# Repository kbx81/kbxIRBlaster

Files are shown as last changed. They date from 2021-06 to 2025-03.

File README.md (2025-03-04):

# kbx IR Blaster

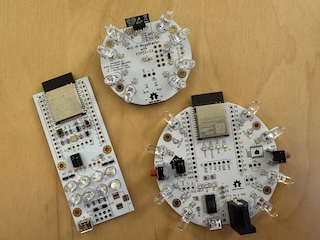
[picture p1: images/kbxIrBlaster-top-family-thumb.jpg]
kbxIrBlasters

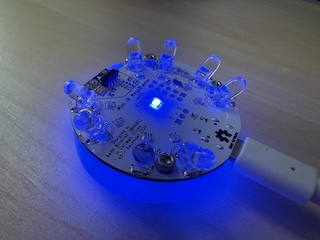
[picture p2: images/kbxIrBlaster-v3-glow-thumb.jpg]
kbxIrBlaster-v3


## What?

Just another ESP32-based IR Blaster. It was designed with [ESPHome](https://esphome.io) in mind but should work fine
with [Tasmota](https://tasmota.github.io/docs/) or any other app, really.

I've created four versions:
- [v4](v4/)
  - Based on ESP32-C6
  - Nearly identical to [v3](v3/) (below) but with minor adjustments/enhancements
- [v3](v3/)
  - Based on ESP32-C3
  - Disc (smaller)
  - One header for (an) off-board emitter(s)
  - Pads for 24 IR LEDs:
    - Eight top-emitting surface mount
    - Eight side-emitting surface mount around the edges of the disc
    - Eight 5 mm LEDs for extra "throw"
- [v2](v2/)
  - Based on ESP32
  - Disc
  - One header for (an) off-board emitter(s)
  - Pads for 16 IR LEDs:
    - Eight top-emitting surface mount
    - Eight 5 mm LEDs for extra "throw" around the perimeter of the PCB
- [v1](v1/)
  - Based on ESP32
  - Rectangular
  - One header for up to four external control channels
  - Pads for up to eight through-hole LEDs, front- and/or back-facing

See the [gallery](GALLERY.md) for more images.

## Why?

After trying this on a perfboard with parts I had laying around, I wanted something more polished and more powerful.
I found [Sparkfun's IR Blaster](https://www.sparkfun.com/products/15031) which is quite nice, tiny and clean but I
quickly realized that its IR output is somewhat weak and would only work if pointed _directly_ at the device it was
intended to control. Rather than hack it up, I chose to draw up my own versions of such a thing. My goal was to make
them substantially more powerful in an effort to "light up a room" with infrared light; that is, you'll probably find
that they work well even when not specifically directed at (if even near) devices you wish to control. I've used an
ESP32 module instead of an ESP8266, as the ESP32 (and its variants) has dedicated hardware for IR data transmission
(the RMT) which makes it more suitable for this purpose, despite that it's otherwise quite overkill.

## How?

Please see the bill of materials (BoM) for the version of interest:
 -  v4 BoM: [Octopart](https://octopart.com/bom-tool/P6YqtNWD), [CSV](v4/kbxIrBlaster_bom.csv)
 -  v3 BoM: [Octopart](https://octopart.com/bom-tool/GUsHZQub), [CSV](v3/kbxIrBlaster_bom.csv)
 -  v2 BoM: [Octopart](https://octopart.com/bom-tool/78rYOXWE), [CSV](v2/kbxIrBlaster_bom.csv)
 -  v1 BoM: [Octopart](https://octopart.com/bom-tool/vDwq4wDr), [CSV](v1/kbxIrBlaster_bom.csv)

I had the PCBs fabricated by [Elecrow](https://www.elecrow.com) but nearly any PCB fabricator should be able to
manufacture these without any issues. I do recommend white soldermask as it will reflect IR best.

The schematic and PCB were drawn in [KiCad](https://www.kicad.org).

## Build Notes

The [v1](v1/) and [v2](v2/) PCBs have a number of solder jumpers on the bottom side that enable each of the FET drivers
to be connected to one of two possible GPIO pins. This allows a single GPIO pin to control all LEDs simultaneously or
they can be broken apart onto separate GPIO pins. Labels on the underside of the PCBs indicate what jumpers are
connected to what LEDs.

_Note that the solder jumpers **must be bridged** one way or the other; if this is not done, the FETs (and consequently
the LEDs they drive) will not activate!_ When you build one, be sure to complete this step or you'll be left in the
dark. (Punny, I know.)

## Add-ons

An FS1000A (such as [this one](https://www.amazon.com/HiLetgo-Wireless-Transmitter-Receiver-Raspberry/dp/B01DKC2EY4/))
or similar 433 MHz transmitter module may be connected as indicated on the PCB allowing the device to double as an RF
remote controller. On the [v1](v1/) PCB, bridge JP6 to enable this and then connect the module to pins 4, 5, and 6 on
J2. On the [v2](v2/) PCB, simply connect the transmitter to J8. When doing so, be sure to orient the module correctly
or tragedy may result.

## Usage

See my [ESPHome-configs](https://github.com/kbx81/esphome-configs) repository for example
[ESPHome](https://esphome.io) configuration you may use with your IR blaster. Enjoy!

 ## Legal stuff and License

The circuit schematics and PCB found here are licensed under the
 [Creative Commons Attribution-ShareAlike 4.0 International License](http://creativecommons.org/licenses/by-sa/4.0/).



_Happy building!_

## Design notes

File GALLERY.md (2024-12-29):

# kbx IR Blaster

## Image Gallery

Click on an image to see the high-resolution version.

kbxIrBlasters

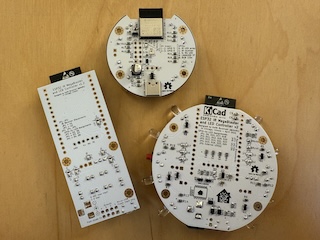
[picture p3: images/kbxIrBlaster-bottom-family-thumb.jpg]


### v3

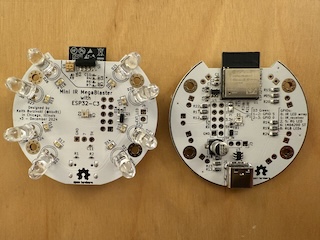
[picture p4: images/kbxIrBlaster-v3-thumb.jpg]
kbxIrBlaster-v3


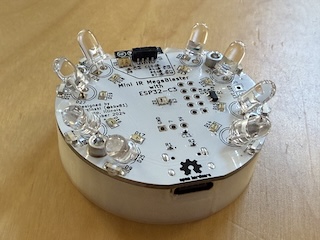
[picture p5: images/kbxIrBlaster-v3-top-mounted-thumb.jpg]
kbxIrBlaster-v3


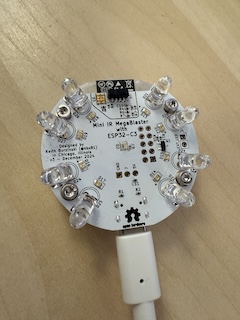
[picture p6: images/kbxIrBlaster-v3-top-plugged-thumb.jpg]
kbxIrBlaster-v3


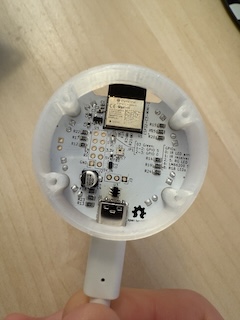
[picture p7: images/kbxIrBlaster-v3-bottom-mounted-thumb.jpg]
kbxIrBlaster-v3


kbxIrBlaster-v3

### v2

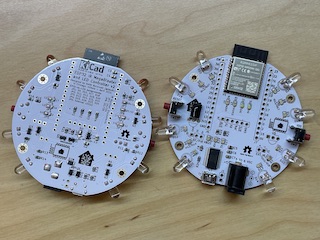
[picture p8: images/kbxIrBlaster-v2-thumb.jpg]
kbxIrBlaster-v2


As seen with the Raspberry Pi NOIR camera:

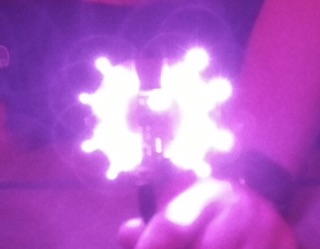
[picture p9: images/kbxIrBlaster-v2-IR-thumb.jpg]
kbxIrBlaster-v2-IR


### v1

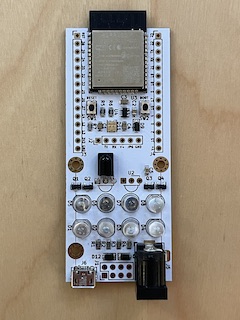
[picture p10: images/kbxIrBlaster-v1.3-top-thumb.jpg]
kbxIrBlaster-v1.3-top


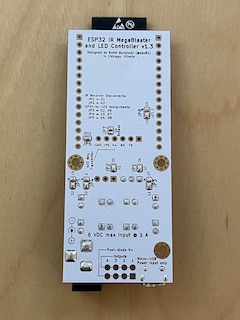
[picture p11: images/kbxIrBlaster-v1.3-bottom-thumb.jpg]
kbxIrBlaster-v1.3-bottom


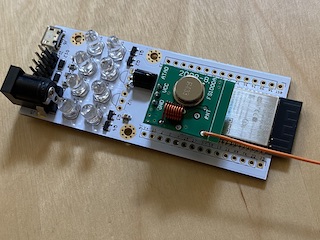
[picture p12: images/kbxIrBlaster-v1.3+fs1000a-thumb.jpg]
kbxIrBlaster+fs1000a


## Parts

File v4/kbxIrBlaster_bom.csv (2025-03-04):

Component | Quantity Per PCB | References | Value | MPN1 | MPN2 | Footprint | Population
1 | 6 | C1 C7 C9 C10 C12 C13 | 100n | CC0402KRX5R6BB104 |  | C_0402_1005Metric
2 | 3 | C2 C8 C11 | 1u | CC0402KRX5R6BB105 |  | C_0402_1005Metric
3 | 1 | C4 | 100u | UWR1A101MCL1GB |  | CP_Elec_5x5.4
4 | 3 | C3 C5 C6 | 10u/20% | CC0603MRX5R6BB106 |  | C_0603_1608Metric
5 | 8 | D12 D13 D14 D15 D16 D17 D18 D19 | APT2012F3C | APT2012F3C |  | LED_0805_2012Metric
6 | 1 | D3 | HW_LED | APB3227SURKZGC |  | LED_Cree-PLCC4_3.2x2.8mm_CCW
7 | 8 | D20 D21 D22 D23 D24 D25 D26 D27 | LTE-4206 | LTE-4206 |  | LED_D5.0mm
8 | 8 | D4 D5 D6 D7 D8 D9 D10 D11 | VSMB10940 | VSMB10940 |  | LED_Kingbright_KPA-3010_3x2x1mm
9 | 2 | D1 D2 | WS2812B | WS2812B-2020 |  | LED_WS2812B-2020_PLCC4_2.0x2.0mm
10 | 1 | FB1 | 600R/2A | MPZ1608S221ATA00 |  | L_0603_1608Metric
11 | 1 | J1 | HRO TYPE-C 31-M-12 | HRO TYPE-C 31-M-12 |  | USB_C_Receptacle_HRO_TYPE-C-31-M-12
12 | 1 | Q1 | PMV164ENEAR | PMV164ENEAR |  | SOT-23
13 | 4 | R24 R25 R26 R27 | 27 | RC0805FR-0727RL |  | R_0805_2012Metric
14 | 4 | R14 R15 R16 R17 | 47 | RC0805JR-0747RL |  | R_0805_2012Metric
15 | 4 | R19 R20 R21 R22 | 56 | RC0805JR-0756RL |  | R_0805_2012Metric
16 | 5 | R3 R10 R11 R12 R18 | 100R | RC0402JR-07100RL |  | R_0402_1005Metric
17 | 2 | R1 R2 | 5k1 | RC0402JR-075K1L |  | R_0402_1005Metric
18 | 8 | R4 R5 R6 R7 R8 R9 R13 R23 | 10k | RC0402JR-0710KL |  | R_0402_1005Metric
19 | 2 | SW1 SW2 | BOOT | KMR2 |  | SW_Push_1P1T_NO_CK_KMR2
20 | 2 | U6 U7 | 74LVC2G157 | 74LVC2G157 |  | VSSOP-8_2.3x2mm_P0.5mm
21 | 1 | U4 | AP2112K-3.3 | AP2112K-3.3TRG1 |  | SOT-23-5
22 | 1 | U1 | ESP32-C6-MINI-1/U | ESP32-C6-MINI-1 |  | ESP32-C6-MINI-1
23 | 1 | U2 | LM66200 | LM66200 |  | SOT-583-8
24 | 1 | U5 | TSOP752xx | TSOP75238 |  | Vishay_TSOP752_Horizontal
25 | 1 | U3 | USBLC6-2SC6 | USBLC6-2SC6 |  | SOT-23-6

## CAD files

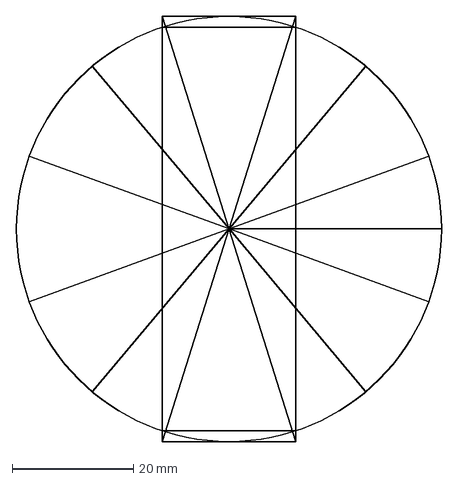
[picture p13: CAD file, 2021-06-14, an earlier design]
v2/kbxIrBlasterDiscPCB.dxf
70.0 x 70.0 mm

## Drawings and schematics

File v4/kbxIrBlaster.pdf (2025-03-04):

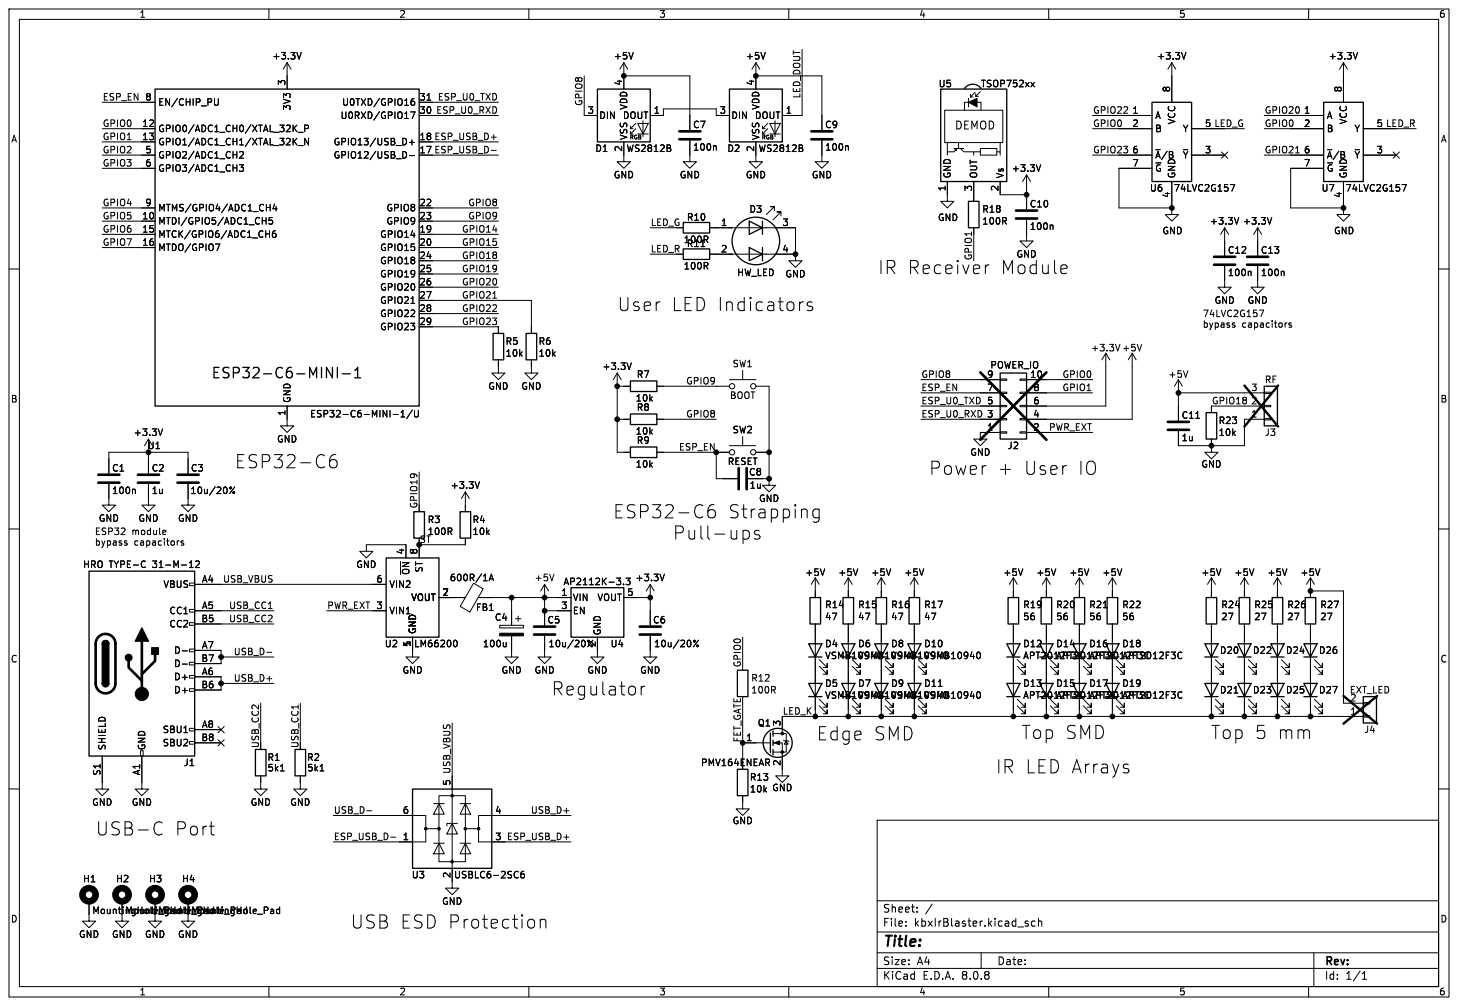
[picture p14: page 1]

3 U0RXD/GPIO17 30 U0TXD/GPIO16 31 GPIO2/ADC1_CH2 5 GPIO3/ADC1_CH3 6 EN/CHIP_PU 8 MTMS/GPIO4/ADC1_CH4 9U1 ESP32-C6-MINI-1/U GND

Id: 1/1 Title: File: kbxIrBlaster.kicad_sch Sheet: / GND

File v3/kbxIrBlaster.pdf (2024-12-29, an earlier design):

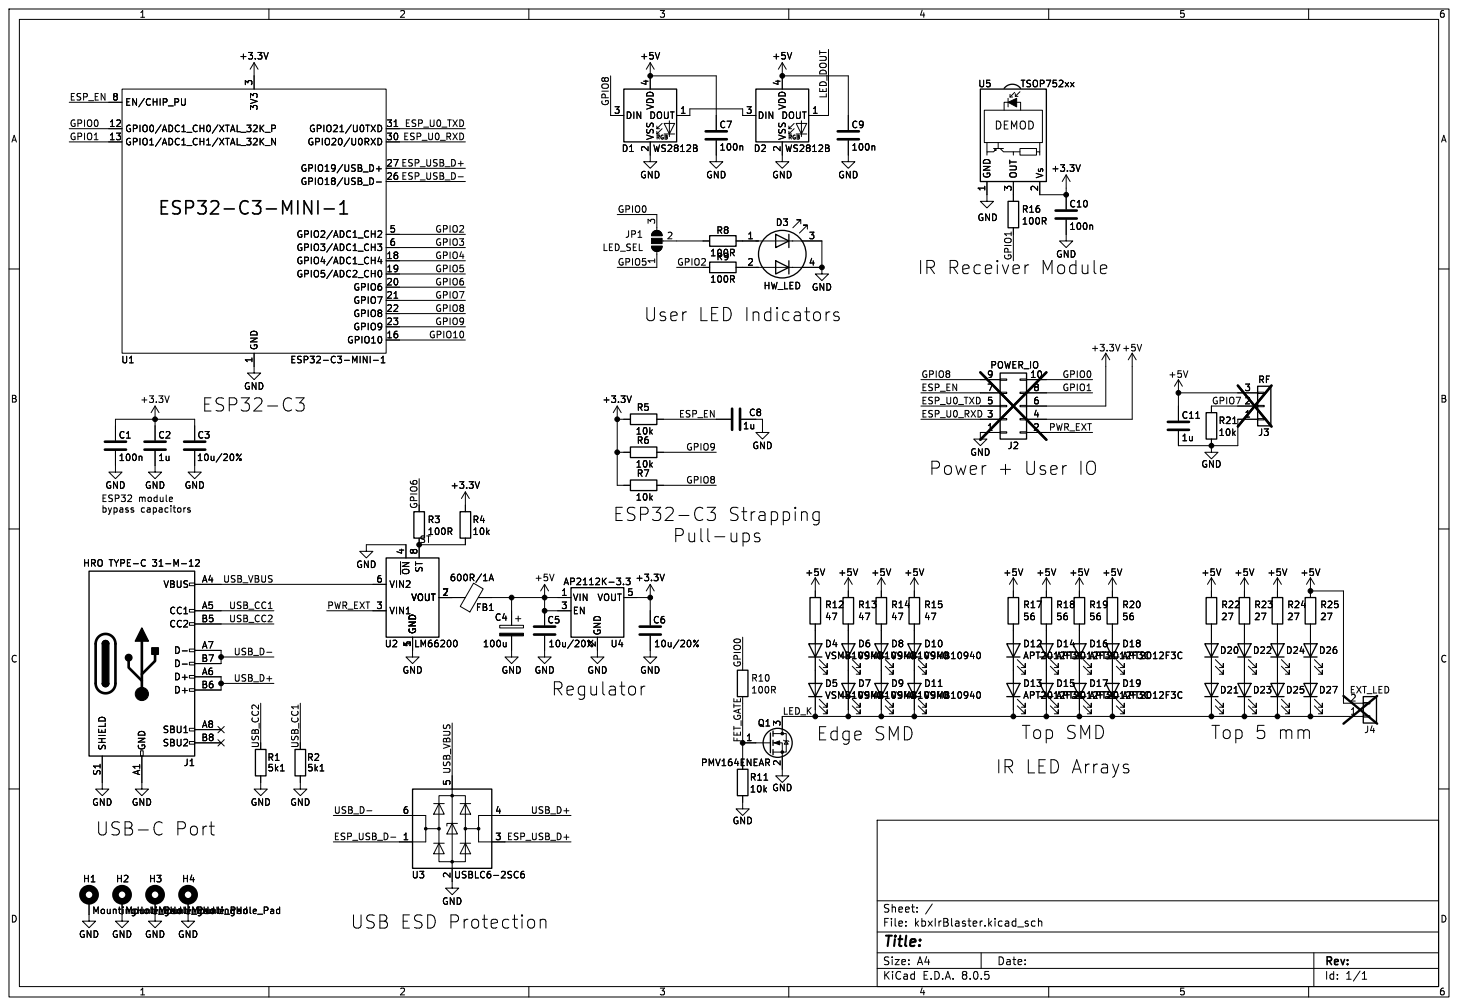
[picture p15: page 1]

2 EN 3 VOUT 5 U4 AP2112K-3.3 GND GND

Id: 1/1 Title: File: kbxIrBlaster.kicad_sch Sheet: /

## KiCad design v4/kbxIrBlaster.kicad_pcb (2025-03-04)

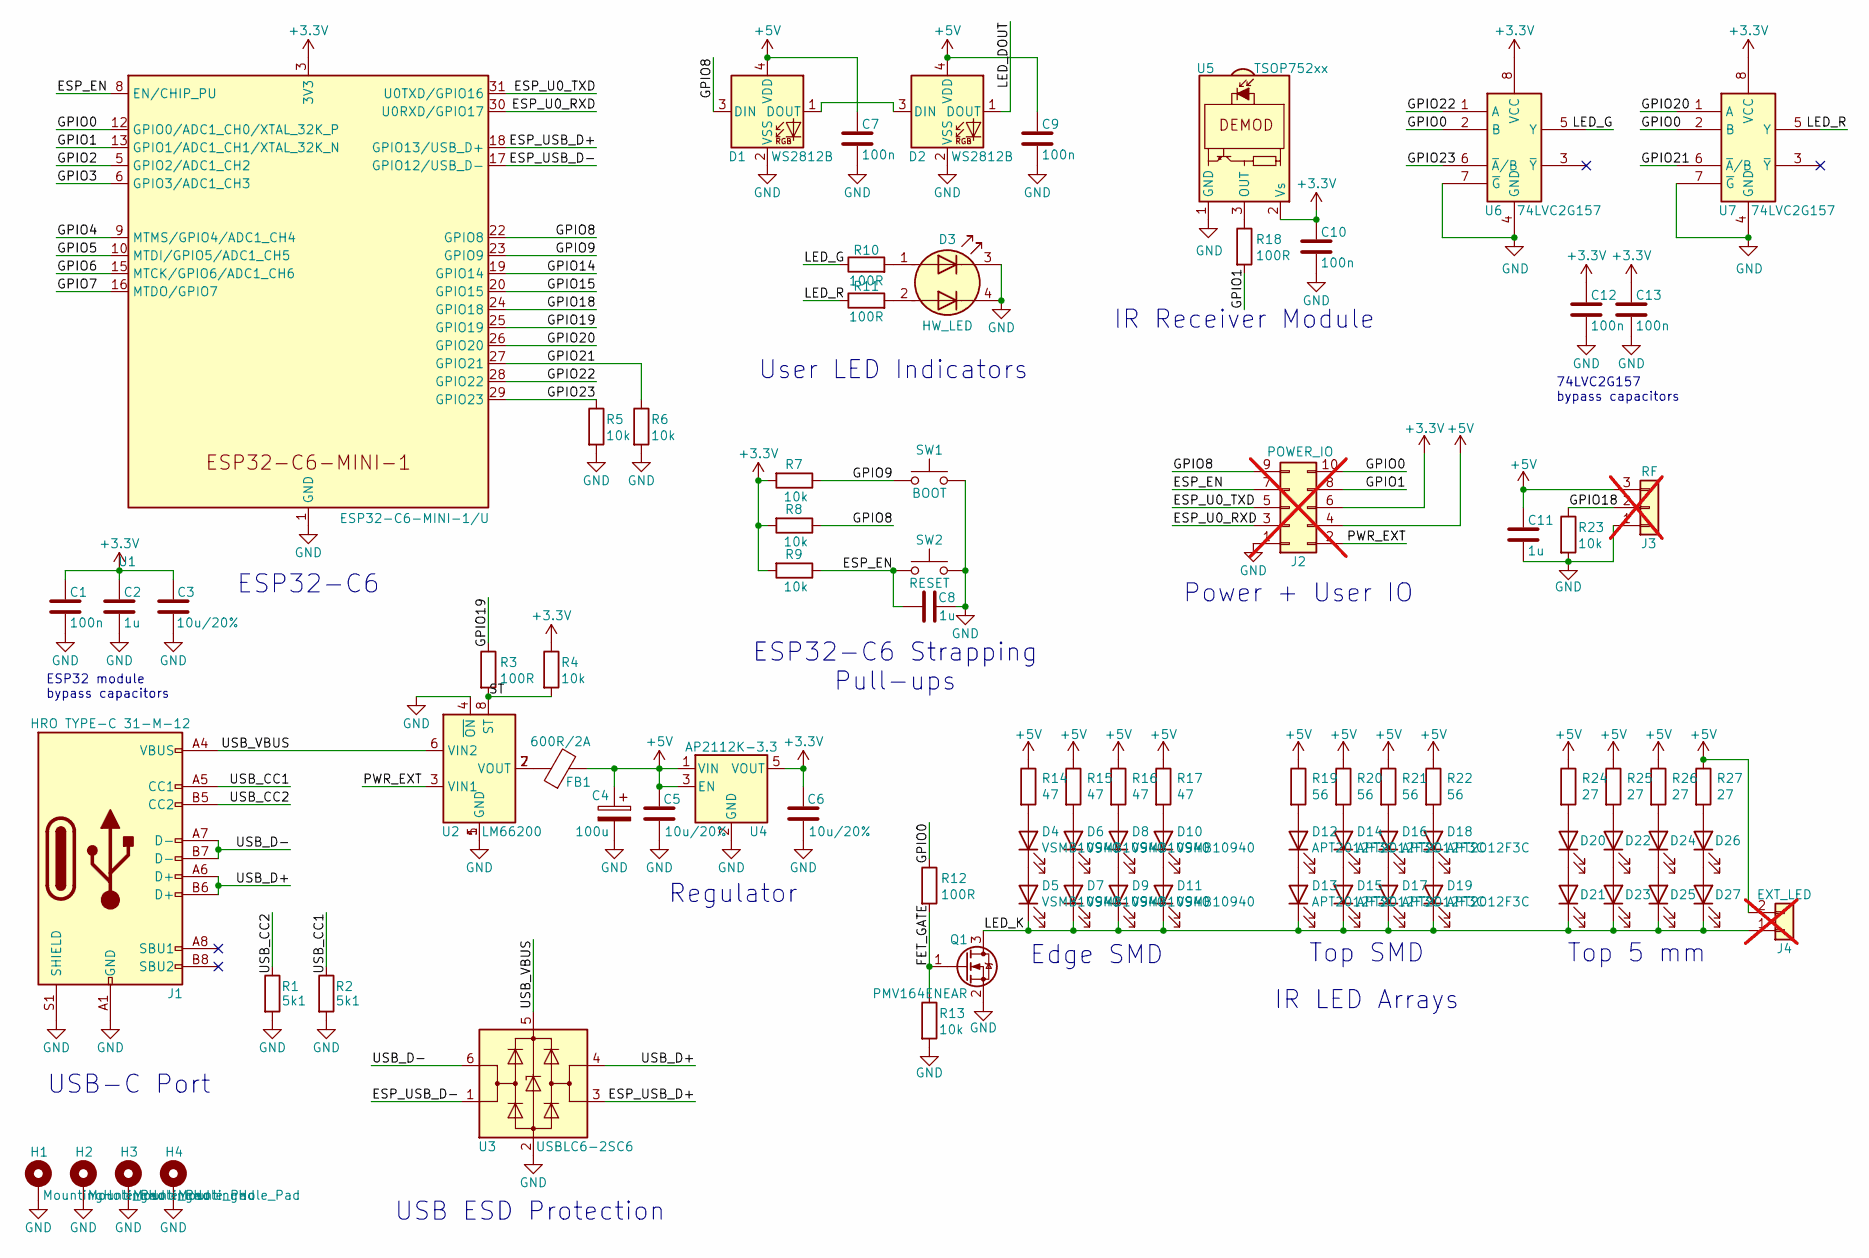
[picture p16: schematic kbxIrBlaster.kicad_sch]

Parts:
C1, C7, C9, C10, C12, C13: 100n; C_0402_1005Metric; MPN1 CC0402KRX5R6BB104
C2, C8, C11: 1u; C_0402_1005Metric; MPN1 CC0402KRX5R6BB105
C3, C5, C6: 10u/20%; C_0603_1608Metric; MPN1 CC0603MRX5R6BB106
C4: 100u; CP_Elec_5x5.4; MPN1 UWR1A101MCL1GB
D1, D2: WS2812B; LED_WS2812B-2020_PLCC4_2.0x2.0mm; MPN1 WS2812B-2020
D3: HW_LED; LED_Cree-PLCC4_3.2x2.8mm_CCW; MPN1 APB3227SURKZGC
D4, D5, D6, D7, D8, D9, D10, D11: VSMB10940; LED_Kingbright_KPA-3010_3x2x1mm; MPN1 VSMB10940
D12, D13, D14, D15, D16, D17, D18, D19: APT2012F3C; LED_0805_2012Metric; MPN1 APT2012F3C
D20, D21, D22, D23, D24, D25, D26, D27: LTE-4206; LED_D5.0mm; MPN1 LTE-4206
FB1: 600R/2A; L_0603_1608Metric; MPN1 MPZ1608S221ATA00
H1, H2, H3, H4: MountingHole_Pad; MountingHole_2.5mm_Pad_Via
J1: HRO TYPE-C 31-M-12; USB_C_Receptacle_HRO_TYPE-C-31-M-12; MPN1 HRO TYPE-C 31-M-12
J2: POWER_IO; PinSocket_2x05_P2.54mm_Vertical; not fitted
J3: RF; PinSocket_1x03_P2.54mm_Vertical; not fitted
J4: EXT_LED; PinSocket_1x02_P2.54mm_Vertical; not fitted
Q1: PMV164ENEAR; SOT-23; MPN1 PMV164ENEAR
R1, R2: 5k1; R_0402_1005Metric; MPN1 RC0402JR-075K1L
R3, R10, R11, R12, R18: 100R; R_0402_1005Metric; MPN1 RC0402JR-07100RL
R4, R5, R6, R7, R8, R9, R13, R23: 10k; R_0402_1005Metric; MPN1 RC0402JR-0710KL
R14, R15, R16, R17: 47; R_0805_2012Metric; MPN1 RC0805JR-0747RL
R19, R20, R21, R22: 56; R_0805_2012Metric; MPN1 RC0805JR-0756RL
R24, R25, R26, R27: 27; R_0805_2012Metric; MPN1 RC0805FR-0727RL
SW1: BOOT; SW_Push_1P1T_NO_CK_KMR2; MPN1 KMR2
SW2: RESET; SW_Push_1P1T_NO_CK_KMR2; MPN1 KMR2
U1: ESP32-C6-MINI-1/U; ESP32-C6-MINI-1; MPN1 ESP32-C6-MINI-1
U2: LM66200; SOT-583-8; MPN1 LM66200
U3: USBLC6-2SC6; SOT-23-6; MPN1 USBLC6-2SC6
U4: AP2112K-3.3; SOT-23-5; MPN1 AP2112K-3.3TRG1
U5: TSOP752xx; Vishay_TSOP752_Horizontal; MPN1 TSOP75238
U6, U7: 74LVC2G157; VSSOP-8_2.3x2mm_P0.5mm; MPN1 74LVC2G157

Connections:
+3.3V: C1.1, C2.1, C3.1, C6.1, C10.1, C12.1, C13.1, J2.6, R4.1, R7.2, R8.2, R9.2, U1.3 (3V3), U4.5 (VOUT), U5.2 (Vs), U6.8 (VCC), U7.8 (VCC)
+5V: C4.1, C5.1, C7.1, C9.1, C11.1, D1.4 (VDD), D2.4 (VDD), FB1.2, J2.4, J3.3, J4.2, R14.1, R15.1, R16.1, R17.1, R19.1, R20.1, R21.1, R22.1, R24.1, R25.1, R26.1, R27.1, U4.1 (VIN), U4.3 (EN)
/ESP_EN: C8.1, J2.7, R9.1, SW2.1, U1.8 (EN/CHIP_PU)
/ESP_U0_RXD: J2.3, U1.30 (U0RXD/GPIO17)
/ESP_U0_TXD: J2.5, U1.31 (U0TXD/GPIO16)
/ESP_USB_D+: U1.18 (GPIO13/USB_D+), U3.3 (I/O2)
/ESP_USB_D-: U1.17 (GPIO12/USB_D-), U3.1 (I/O1)
/FET_GATE: Q1.1 (G), R12.2, R13.1
/GPIO0: J2.10, R12.1, U1.12 (GPIO0/ADC1_CH0/XTAL_32K_P), U6.2 (B), U7.2 (B)
/GPIO1: J2.8, R18.2, U1.13 (GPIO1/ADC1_CH1/XTAL_32K_N)
/GPIO2: U1.5 (GPIO2/ADC1_CH2)
/GPIO3: U1.6 (GPIO3/ADC1_CH3)
/GPIO4: U1.9 (MTMS/GPIO4/ADC1_CH4)
/GPIO5: U1.10 (MTDI/GPIO5/ADC1_CH5)
/GPIO6: U1.15 (MTCK/GPIO6/ADC1_CH6)
/GPIO7: U1.16 (MTDO/GPIO7)
/GPIO8: D1.3 (DIN), J2.9, R8.1, U1.22 (GPIO8)
/GPIO9: R7.1, SW1.1, U1.23 (GPIO9)
/GPIO14: U1.19 (GPIO14)
/GPIO15: U1.20 (GPIO15)
/GPIO18: J3.2, R23.1, U1.24 (GPIO18)
/GPIO19: R3.1, U1.25 (GPIO19)
/GPIO20: U1.26 (GPIO20), U7.1 (A)
/GPIO21: R6.1, U1.27 (GPIO21), U7.6 (~A/B)
/GPIO22: U1.28 (GPIO22), U6.1 (A)
/GPIO23: R5.1, U1.29 (GPIO23), U6.6 (~A/B)
/LED_DOUT: D2.1 (DOUT)
/LED_G: R10.1, U6.5 (Y)
/LED_K: D5.1 (K), D7.1 (K), D9.1 (K), D11.1 (K), D13.1 (K), D15.1 (K), D17.1 (K), D19.1 (K), D21.1 (K), D23.1 (K), D25.1 (K), D27.1 (K), J4.1, Q1.3 (D)
/LED_R: R11.1, U7.5 (Y)
/PWR_EXT: J2.2, U2.3 (VIN1)
/ST: R3.2, R4.2, U2.8 (ST)
/USB_CC1: J1.A5 (CC1), R2.1
/USB_CC2: J1.B5 (CC2), R1.1
/USB_D+: J1.A6 (D+), J1.B6 (D+), U3.4 (I/O2)
/USB_D-: J1.A7 (D-), J1.B7 (D-), U3.6 (I/O1)
/USB_VBUS: J1.A4 (VBUS), J1.A9 (VBUS), J1.B4 (VBUS), J1.B9 (VBUS), U2.6 (VIN2), U3.5 (VBUS)
GND: C1.2, C2.2, C3.2, C4.2, C5.2, C6.2, C7.2, C8.2, C9.2, C10.2, C11.2, C12.2, C13.2, D1.2 (VSS), D2.2 (VSS), D3.3 (K1), D3.4 (K2), H1.1, H2.1, H3.1, H4.1, J1.A1 (GND), J1.A12 (GND), J1.B1 (GND), J1.B12 (GND), J1.S1 (SHIELD), J2.1, J3.1, Q1.2 (S), R1.2, R2.2, R5.2, R6.2, R13.2, R23.2, SW1.2, SW2.2, U1.1 (GND), U1.2 (GND), U1.11 (GND), U1.14 (GND), U1.36 (GND), U1.37 (GND), U1.38 (GND), U1.39 (GND), U1.40 (GND), U1.41 (GND), U1.42 (GND), U1.43 (GND), U1.44 (GND), U1.45 (GND), U1.46 (GND), U1.47 (GND), U1.48 (GND), U1.49 (GND), U1.50 (GND), U1.51 (GND), U1.52 (GND), U1.53 (GND), U2.1 (GND), U2.4 (~ON), U2.5 (GND), U3.2 (GND), U4.2 (GND), U5.1 (GND), U5.4 (GND), U6.4 (GND), U6.7 (~G), U7.4 (GND), U7.7 (~G)
unnamed: D1.1 (DOUT), D2.3 (DIN)
unnamed: D3.1 (A1), R10.2
unnamed: D3.2 (A2), R11.2
unnamed: D4.2 (A), R14.2
unnamed: D4.1 (K), D5.2 (A)
unnamed: D6.2 (A), R15.2
unnamed: D6.1 (K), D7.2 (A)
unnamed: D8.2 (A), R16.2
unnamed: D8.1 (K), D9.2 (A)
unnamed: D10.2 (A), R17.2
unnamed: D10.1 (K), D11.2 (A)
unnamed: D12.2 (A), R19.2
unnamed: D12.1 (K), D13.2 (A)
unnamed: D14.2 (A), R20.2
unnamed: D14.1 (K), D15.2 (A)
unnamed: D16.2 (A), R21.2
unnamed: D16.1 (K), D17.2 (A)
unnamed: D18.2 (A), R22.2
unnamed: D18.1 (K), D19.2 (A)
unnamed: D20.2 (A), R24.2
unnamed: D20.1 (K), D21.2 (A)
unnamed: D22.2 (A), R25.2
unnamed: D22.1 (K), D23.2 (A)
unnamed: D24.2 (A), R26.2
unnamed: D24.1 (K), D25.2 (A)
unnamed: D26.2 (A), R27.2
unnamed: D26.1 (K), D27.2 (A)
unnamed: FB1.1, U2.2 (VOUT), U2.7 (VOUT)
unnamed: R18.1, U5.3 (OUT)

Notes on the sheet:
Top SMD
Edge SMD
74LVC2G157 bypass capacitors
User LED Indicators
Power + User IO
ESP32-C6
USB-C Port
USB ESD Protection
Top 5 mm
ESP32-C6 Strapping Pull-ups
IR Receiver Module
IR LED Arrays
Regulator
ESP32 module bypass capacitors

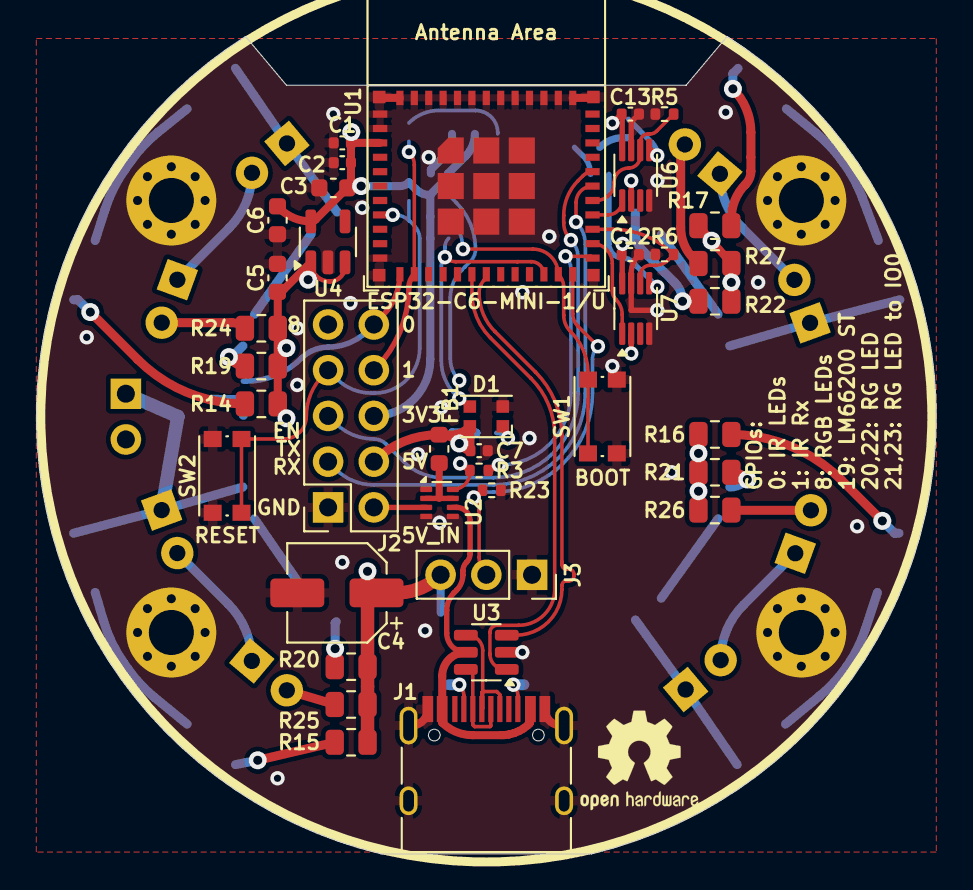
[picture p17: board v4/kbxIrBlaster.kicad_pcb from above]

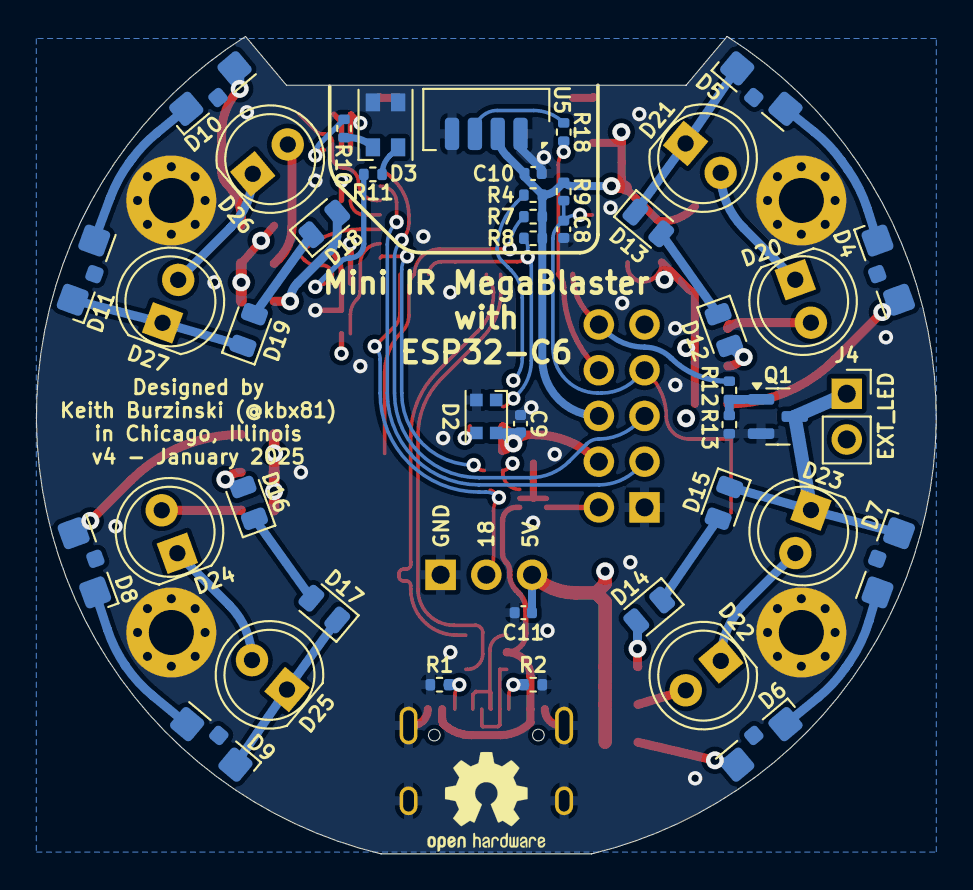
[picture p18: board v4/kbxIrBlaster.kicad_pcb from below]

Board: 4 copper layers, 50.0 x 45.4 mm, 86 parts (44 on the bottom side), 58 nets.

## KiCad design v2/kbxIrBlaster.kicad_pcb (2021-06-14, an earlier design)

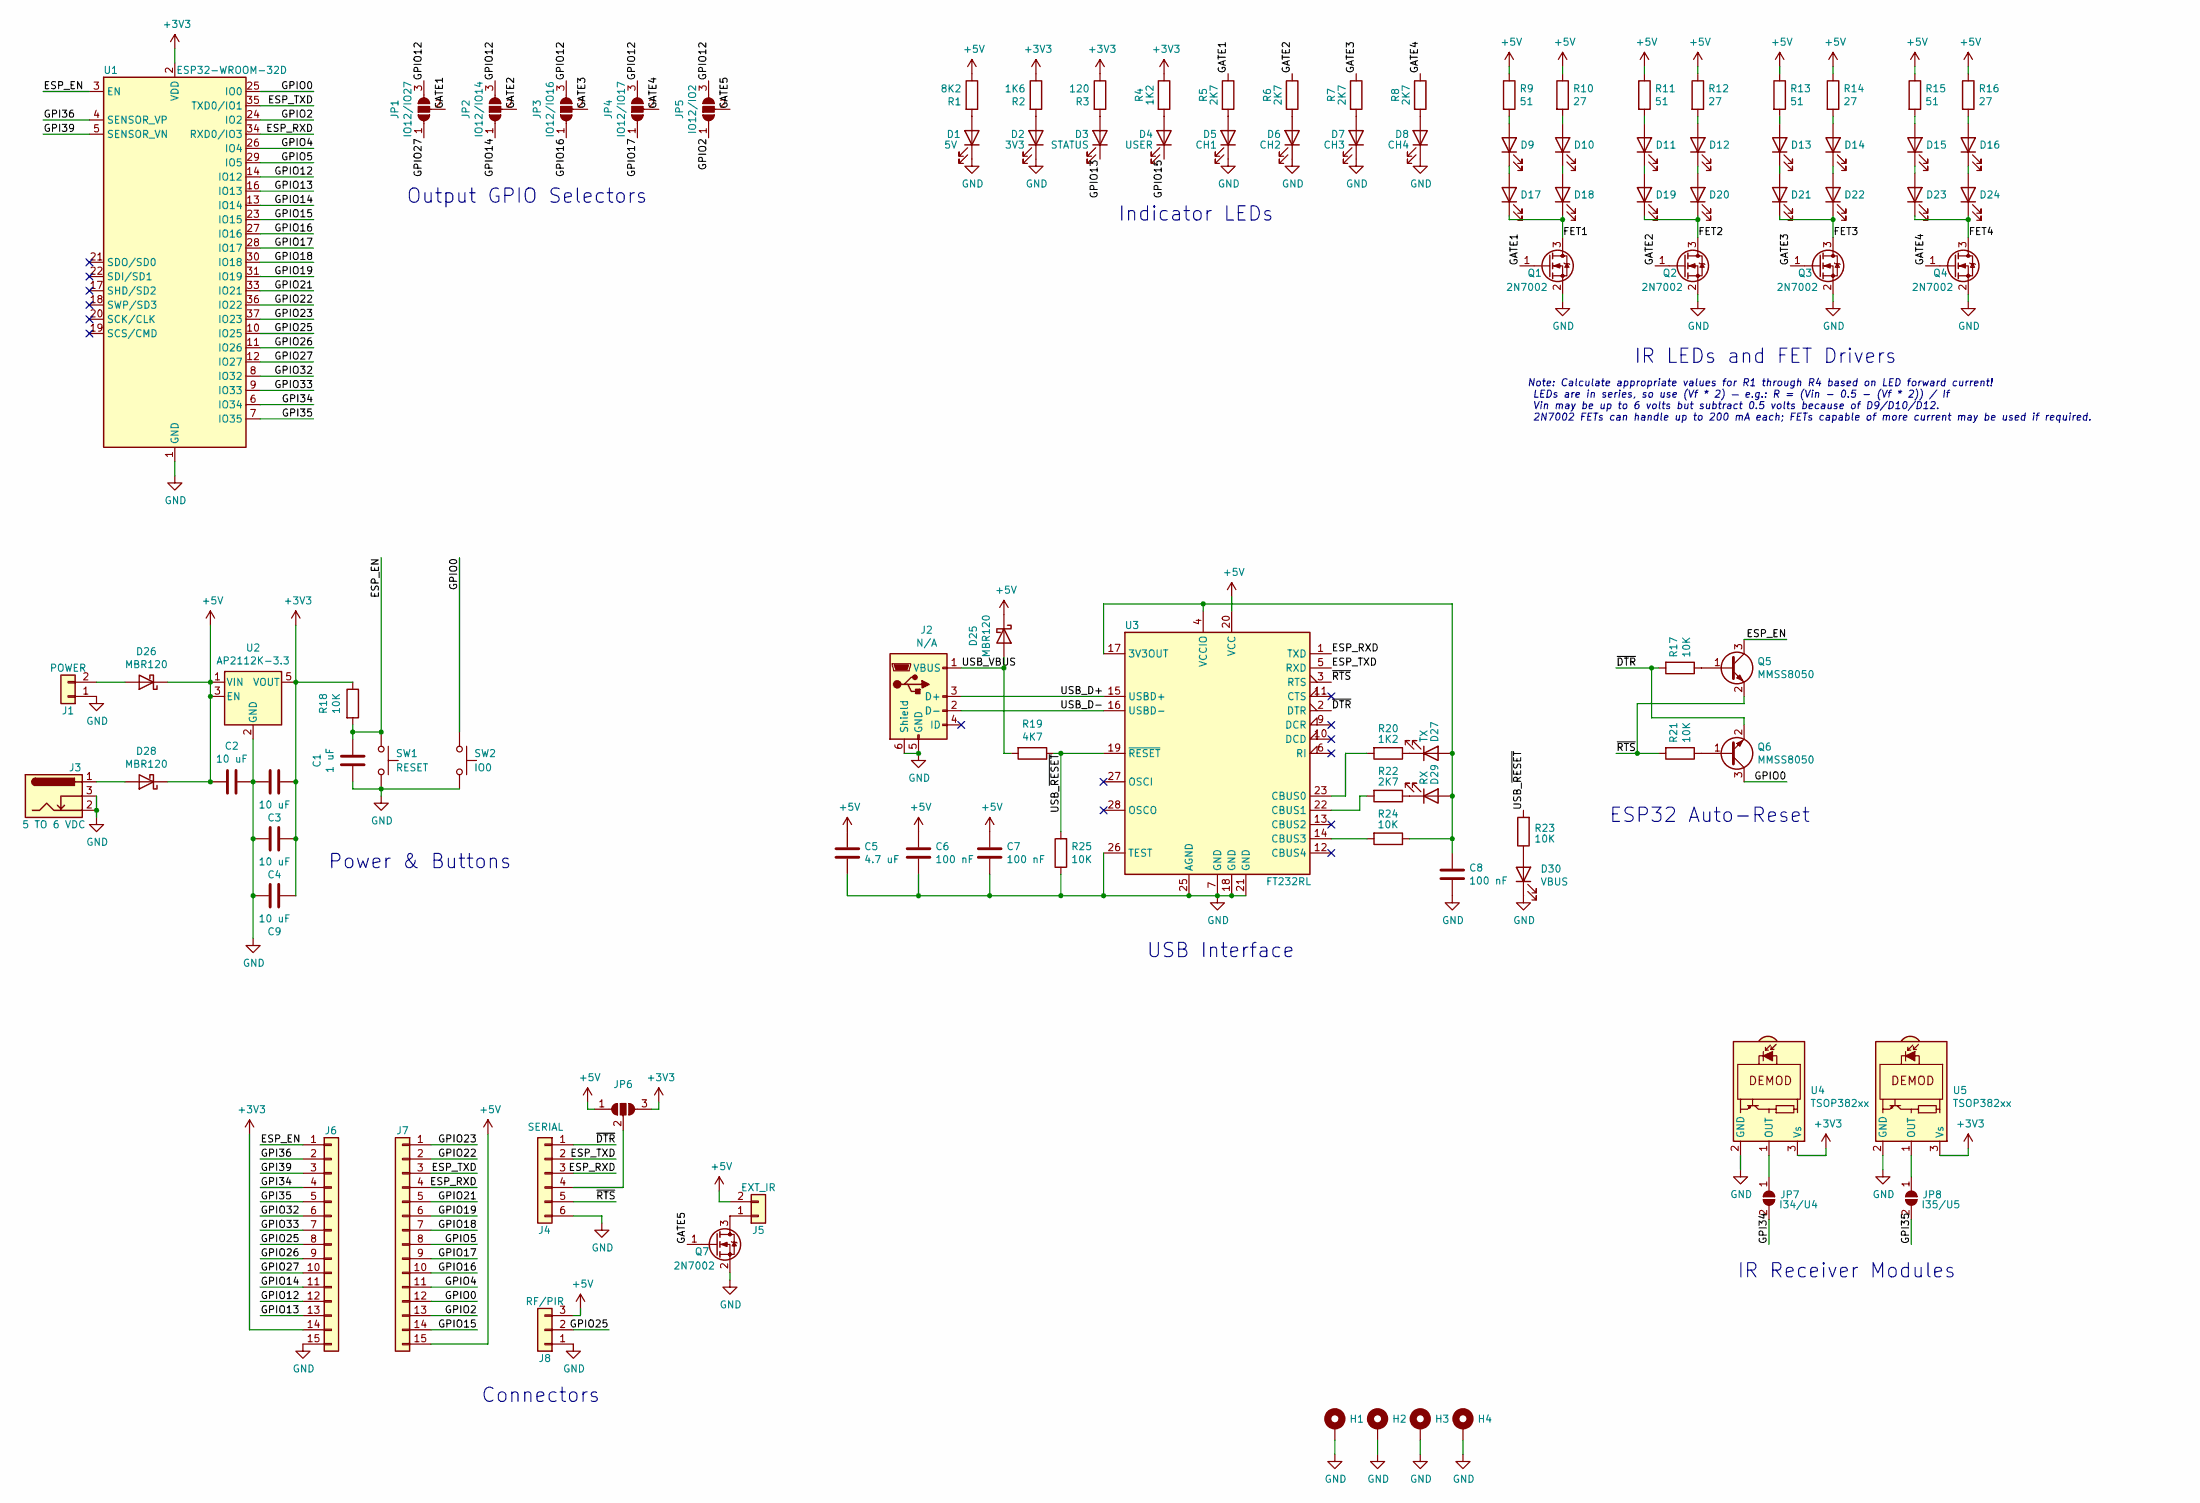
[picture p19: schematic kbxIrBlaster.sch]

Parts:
C1: 1 uF; C_0805_2012Metric; MPN1 C0805C105K4RACTU
C2, C3, C4, C9: 10 uF; C_0805_2012Metric; MPN1 GRM21BC81C106ME15L
C5: 4.7 uF; C_0805_2012Metric; MPN1 C2012X5R1H475K125AB
C6, C7, C8: 100 nF; C_0805_2012Metric; MPN1 CC0805KRX7R7BB104
D1: 5V; LED_0805_2012Metric; MPN1 LSM0805543V
D2: 3V3; LED_0805_2012Metric; MPN1 LSM0805543V
D3: STATUS; LED_0805_2012Metric; MPN1 APT2012SECK
D4: USER; LED_0805_2012Metric; MPN1 APT2012SYCK
D5: CH1; LED_0805_2012Metric; MPN1 APT2012EC
D6: CH2; LED_0805_2012Metric; MPN1 APT2012EC
D7: CH3; LED_0805_2012Metric; MPN1 APT2012EC
D8: CH4; LED_0805_2012Metric; MPN1 APT2012EC
D9, D17: CH1; LED_0805_2012Metric; MPN1 APT2012F3C
D10, D18: CH1; LED_D5.0mm; MPN1 LTE-4206
D11, D19: CH2; LED_0805_2012Metric; MPN1 APT2012F3C
D12, D20: CH2; LED_D5.0mm; MPN1 LTE-4206
D13, D21: CH3; LED_0805_2012Metric; MPN1 APT2012F3C
D14, D22: CH3; LED_D5.0mm; MPN1 LTE-4206
D15, D23: CH4; LED_0805_2012Metric; MPN1 APT2012F3C
D16, D24: CH4; LED_D5.0mm; MPN1 LTE-4206
D25, D26, D28: MBR120; D_SOD-123F; MPN1 MBR120VLSFT1G
D27: TX; LED_0805_2012Metric; MPN1 APT2012VBC/D
D29: RX; LED_0805_2012Metric; MPN1 APT2012EC
D30: VBUS; LED_0805_2012Metric; MPN1 APT2012ZGCK
H1, H2, H3, H4: -; MountingHole_2.5mm_Pad_Via
J1: POWER; PinHeader_1x02_P2.54mm_Vertical
J2: N/A; USB_Micro-B_Molex-105017-0001; MPN1 105017-0001
J3: 5 TO 6 VDC; BarrelJack_Horizontal; MPN1 163-179PH-EX
J4: SERIAL; PinHeader_1x06_P2.54mm_Vertical
J5: EXT_IR; PinHeader_1x02_P2.54mm_Vertical
J6, J7: IO; PinHeader_1x15_P2.54mm_Vertical
J8: RF/PIR; PinHeader_1x03_P2.54mm_Vertical
JP1: IO12/IO27; SolderJumper-3_P1.3mm_Open_RoundedPad1.0x1.5mm
JP2: IO12/IO14; SolderJumper-3_P1.3mm_Open_RoundedPad1.0x1.5mm
JP3: IO12/IO16; SolderJumper-3_P1.3mm_Open_RoundedPad1.0x1.5mm
JP4: IO12/IO17; SolderJumper-3_P1.3mm_Open_RoundedPad1.0x1.5mm
JP5: IO12/IO2; SolderJumper-3_P1.3mm_Open_RoundedPad1.0x1.5mm
JP6: 5V/3V3; SolderJumper-3_P1.3mm_Open_RoundedPad1.0x1.5mm
JP7: I34/U4; SolderJumper-2_P1.3mm_Open_RoundedPad1.0x1.5mm
JP8: I35/U5; SolderJumper-2_P1.3mm_Open_RoundedPad1.0x1.5mm
Q1, Q2, Q3, Q4, Q7: 2N7002; SOT-23; MPN1 2N7002-7-F
Q5, Q6: MMSS8050; SOT-23; MPN1 MMSS8050
R1: 8K2; R_0805_2012Metric; MPN1 RT0805FRE078K2L
R2: 1K6; R_0805_2012Metric; MPN1 RT0805FRE071K6L
R3: 120; R_0805_2012Metric; MPN1 RT0805FRE07120RL
R4, R20: 1K2; R_0805_2012Metric; MPN1 RT0805FRE072K7L
R5, R6, R7, R8, R22: 2K7; R_0805_2012Metric; MPN1 RT0805FRE072K7L
R9, R11, R13, R15: 51; R_0805_2012Metric; MPN1 RC0805FR-0751RL
R10, R12, R14, R16: 27; R_0805_2012Metric; MPN1 RC0805FR-0727RL
R17, R18, R21, R23, R24, R25: 10K; R_0805_2012Metric; MPN1 RC0805FR-0710KL
R19: 4K7; R_0805_2012Metric; MPN1 RT0805FRE074K7L
SW1: RESET; SW_Tactile_SPST_Angled_PTS645Vx58-2LFS; MPN1 PTS645VK582LFS
SW2: IO0; SW_Tactile_SPST_Angled_PTS645Vx58-2LFS; MPN1 PTS645VK582LFS
U1: ESP32-WROOM-32D; ESP32-WROOM-32; MPN1 ESP32-WROOM-32D
U2: AP2112K-3.3; SOT-23-5; MPN1 AP2112M-3.3TRG1
U3: FT232RL; SSOP-28_5.3x10.2mm_P0.65mm; MPN1 FT232RL
U4: TSOP382xx; Vishay_MINICAST-3Pin; MPN1 TSOP38238
U5: TSOP382xx; Vishay_MINICAST-3Pin; MPN1 TSOP38256

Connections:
+3V3: C3.2, C4.2, C9.2, J6.14, JP6.3 (B), R2.1, R3.1, R4.1, R18.1, U1.2 (VDD), U2.5 (VOUT), U4.3 (Vs), U5.3 (Vs)
+5V: C2.2, C5.1, C6.1, C7.1, D25.1 (K), D26.1 (K), D28.1 (K), J5.2, J7.15, J8.3, JP6.1 (A), R1.1, R9.1, R10.1, R11.1, R12.1, R13.1, R14.1, R15.1, R16.1, U2.1 (VIN), U2.3 (EN), U3.20 (VCC)
/ESP_EN: C1.1, J6.1, Q5.3 (C), R18.2, SW1.1, U1.3 (EN)
/ESP_RXD: J4.3, J7.4, U1.34 (RXD0/IO3), U3.1 (TXD)
/ESP_TXD: J4.2, J7.3, U1.35 (TXD0/IO1), U3.5 (RXD)
/FET1: D17.1 (K), D18.1 (K), Q1.3 (D)
/FET2: D19.1 (K), D20.1 (K), Q2.3 (D)
/FET3: D21.1 (K), D22.1 (K), Q3.3 (D)
/FET4: D23.1 (K), D24.1 (K), Q4.3 (D)
/GATE1: JP1.2 (C), Q1.1 (G), R5.1
/GATE2: JP2.2 (C), Q2.1 (G), R6.1
/GATE3: JP3.2 (C), Q3.1 (G), R7.1
/GATE4: JP4.2 (C), Q4.1 (G), R8.1
/GATE5: JP5.2 (C), Q7.1 (G)
/GPI34: J6.4, JP7.2 (B), U1.6 (IO34)
/GPI35: J6.5, JP8.2 (B), U1.7 (IO35)
/GPI36: J6.2, U1.4 (SENSOR_VP)
/GPI39: J6.3, U1.5 (SENSOR_VN)
/GPIO0: J7.12, Q6.3 (C), SW2.1, U1.25 (IO0)
/GPIO2: J7.13, JP5.1 (A), U1.24 (IO2)
/GPIO4: J7.11, U1.26 (IO4)
/GPIO5: J7.8, U1.29 (IO5)
/GPIO12: J6.12, JP1.3 (B), JP2.3 (B), JP3.3 (B), JP4.3 (B), JP5.3 (B), U1.14 (IO12)
/GPIO13: D3.1 (K), J6.13, U1.16 (IO13)
/GPIO14: J6.11, JP2.1 (A), U1.13 (IO14)
/GPIO15: D4.1 (K), J7.14, U1.23 (IO15)
/GPIO16: J7.10, JP3.1 (A), U1.27 (IO16)
/GPIO17: J7.9, JP4.1 (A), U1.28 (IO17)
/GPIO18: J7.7, U1.30 (IO18)
/GPIO19: J7.6, U1.31 (IO19)
/GPIO21: J7.5, U1.33 (IO21)
/GPIO22: J7.2, U1.36 (IO22)
/GPIO23: J7.1, U1.37 (IO23)
/GPIO25: J6.8, J8.2, U1.10 (IO25)
/GPIO26: J6.9, U1.11 (IO26)
/GPIO27: J6.10, JP1.1 (A), U1.12 (IO27)
/GPIO32: J6.6, U1.8 (IO32)
/GPIO33: J6.7, U1.9 (IO33)
/USB_D+: J2.3 (D+), U3.15 (USBD+)
/USB_D-: J2.2 (D-), U3.16 (USBD-)
/USB_VBUS: D25.2 (A), J2.1 (VBUS), R19.2
/USB_~RESET: R19.1, R23.2, R25.2, U3.19 (~RESET~)
/~DTR: J4.1, Q6.2 (E), R17.2, U3.2 (DTR)
/~RTS: J4.5, Q5.2 (E), R21.2, U3.3 (RTS)
GND: C1.2, C2.1, C3.1, C4.1, C5.2, C6.2, C7.2, C8.2, C9.1, D1.1 (K), D2.1 (K), D5.1 (K), D6.1 (K), D7.1 (K), D8.1 (K), D30.1 (K), H1.1, H2.1, H3.1, H4.1, J1.1, J2.5 (GND), J2.6 (Shield), J3.2, J3.3, J4.6, J6.15, J8.1, Q1.2 (S), Q2.2 (S), Q3.2 (S), Q4.2 (S), Q7.2 (S), R25.1, SW1.2, SW2.2, U1.1 (GND), U1.15 (GND), U1.38 (GND), U1.39 (GND), U2.2 (GND), U3.7 (GND), U3.18 (GND), U3.21 (GND), U3.25 (AGND), U3.26 (TEST), U4.2 (GND), U5.2 (GND)
unnamed: C8.1, D27.2 (A), D29.2 (A), R24.1, U3.4 (VCCIO), U3.17 (3V3OUT)
unnamed: D1.2 (A), R1.2
unnamed: D2.2 (A), R2.2
unnamed: D3.2 (A), R3.2
unnamed: D4.2 (A), R4.2
unnamed: D5.2 (A), R5.2
unnamed: D6.2 (A), R6.2
unnamed: D7.2 (A), R7.2
unnamed: D8.2 (A), R8.2
unnamed: D9.2 (A), R9.2
unnamed: D10.1 (K), D18.2 (A)
unnamed: D10.2 (A), R10.2
unnamed: D11.1 (K), D19.2 (A)
unnamed: D11.2 (A), R11.2
unnamed: D12.1 (K), D20.2 (A)
unnamed: D12.2 (A), R12.2
unnamed: D13.1 (K), D21.2 (A)
unnamed: D13.2 (A), R13.2
unnamed: D14.1 (K), D22.2 (A)
unnamed: D14.2 (A), R14.2
unnamed: D15.1 (K), D23.2 (A)
unnamed: D15.2 (A), R15.2
unnamed: D16.1 (K), D24.2 (A)
unnamed: D16.2 (A), R16.2
unnamed: D9.1 (K), D17.2 (A)
unnamed: D26.2 (A), J1.2
unnamed: D27.1 (K), R20.1
unnamed: D28.2 (A), J3.1
unnamed: D29.1 (K), R22.1
unnamed: D30.2 (A), R23.1
unnamed: J4.4, JP6.2 (C)
unnamed: J5.1, Q7.3 (D)
unnamed: JP7.1 (A), U4.1 (OUT)
unnamed: JP8.1 (A), U5.1 (OUT)
unnamed: Q5.1 (B), R17.1
unnamed: Q6.1 (B), R21.1
unnamed: R20.2, U3.23 (CBUS0)
unnamed: R22.2, U3.22 (CBUS1)
unnamed: R24.2, U3.14 (CBUS3)

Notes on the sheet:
IR Receiver Modules
Power & Buttons
ESP32 Auto-Reset
USB Interface
IR LEDs and FET Drivers
Connectors
Note: Calculate appropriate values for R1 through R4 based on LED forward current! LEDs are in series, so use (Vf * 2) — e.g.: R = (Vin - 0.5 - (Vf * 2)) / If Vin may be up to 6 volts but subtract 0.5 volts because of D9/D10/D12. 2N7002 FETs can handle up to 200 mA each; FETs capable of more curren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
Indicator LEDs
Output GPIO Selectors

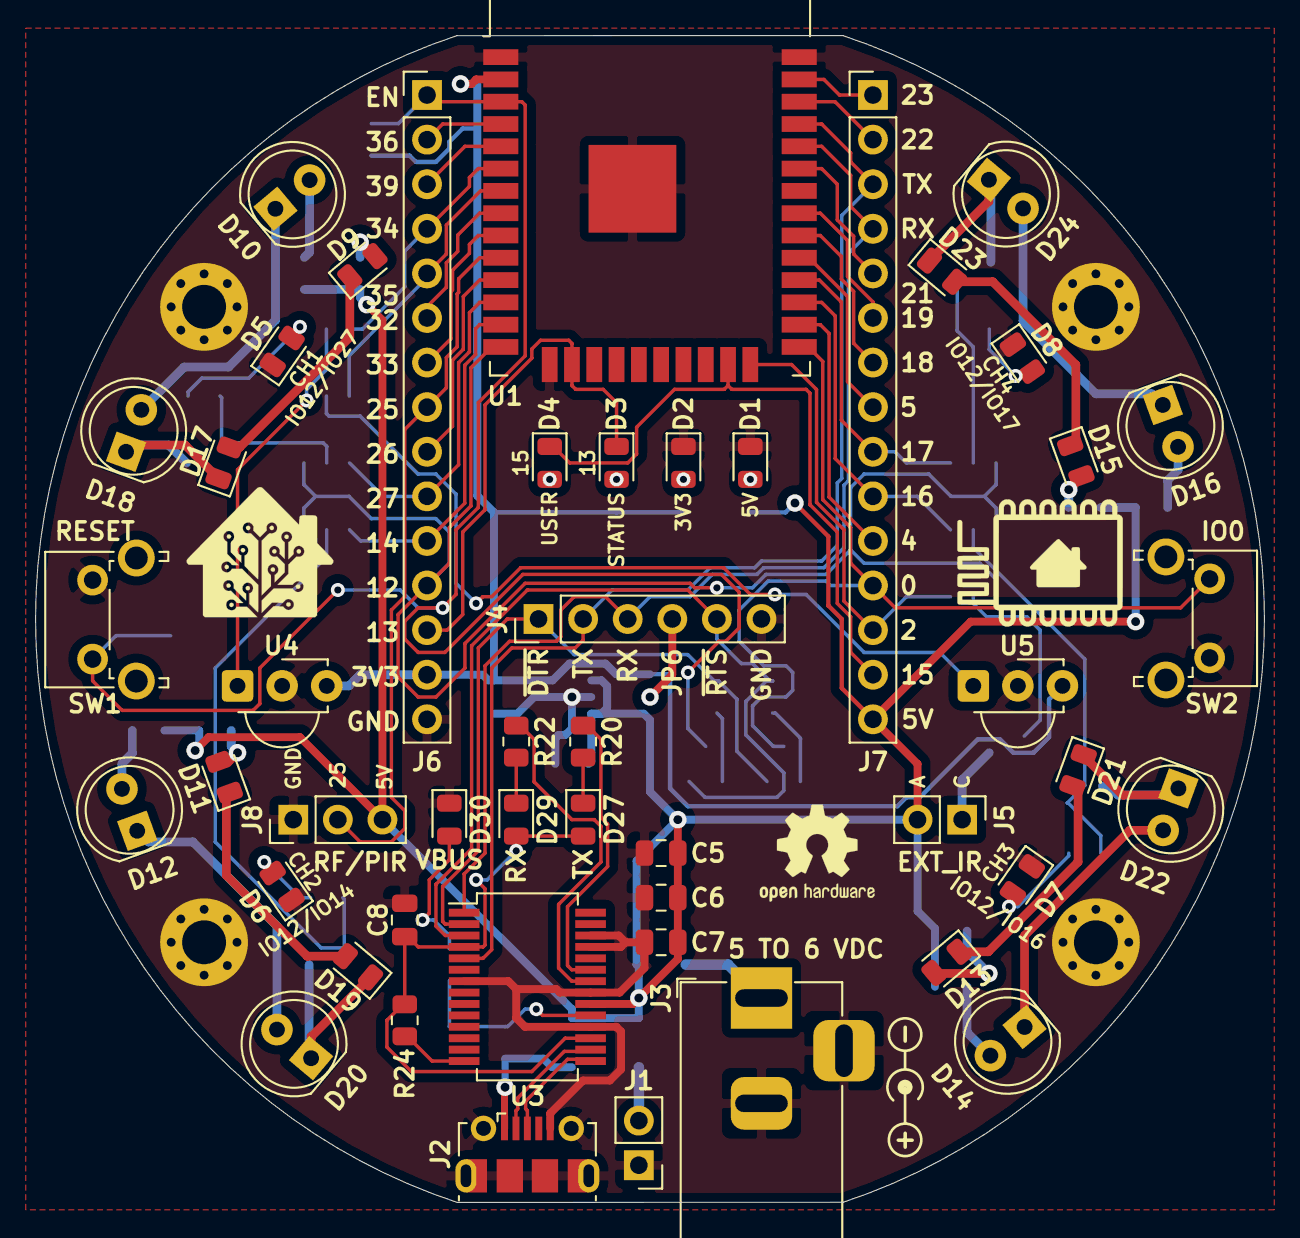
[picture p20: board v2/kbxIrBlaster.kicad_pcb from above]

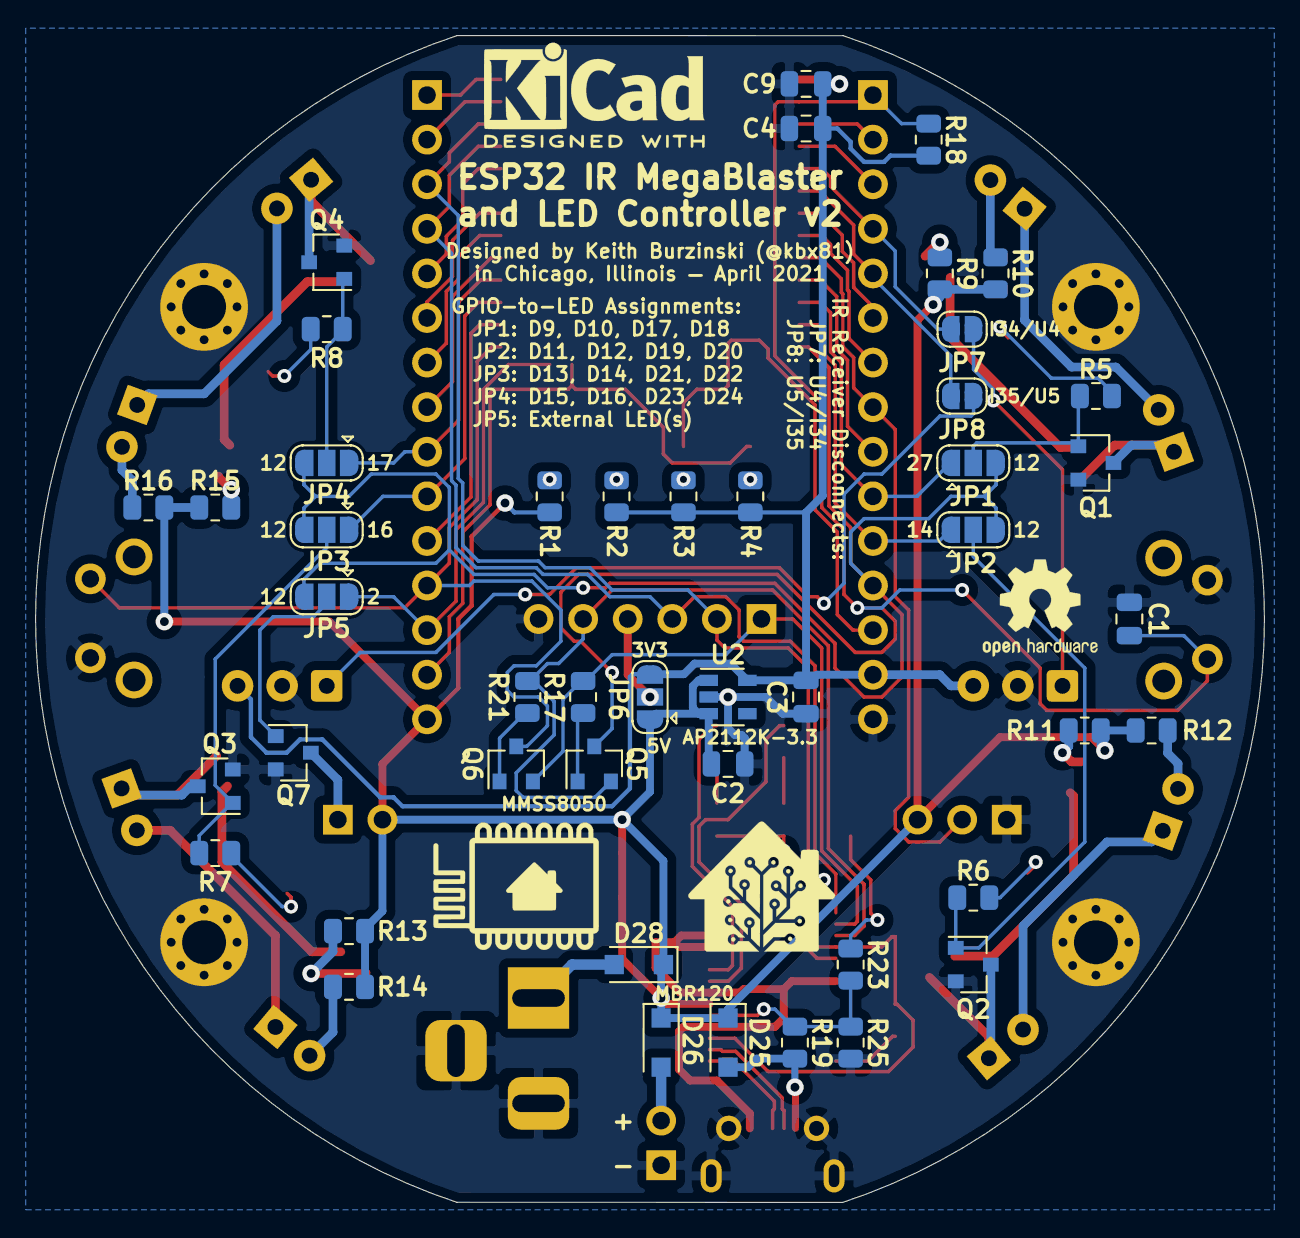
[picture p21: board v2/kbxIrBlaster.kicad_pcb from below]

Board: 2 copper layers, 70.0 x 66.5 mm, 98 parts (46 on the bottom side), 84 nets.

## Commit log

2020-04-03 BoM fix
2020-04-09 PCB refinements
    [kbxIrBlaster-B_Cu.gbr, kbxIrBlaster-B_Mask.gbr, kbxIrBlaster-B_Paste.gbr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]
2021-06-14 Add v2 and other updates
    [kbxIrBlaster-B_Cu.gbr, kbxIrBlaster-B_Mask.gbr, kbxIrBlaster-B_Paste.gbr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]
2022-04-15 v3 initial commit
    [kbxIrBlaster-B_Cu.gbr, kbxIrBlaster-B_Mask.gbr, kbxIrBlaster-B_Paste.gbr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]
2024-12-29 Update with v3
    [kbxIrBlaster-B_Cu.gbr, kbxIrBlaster-B_Mask.gbr, kbxIrBlaster-B_Paste.gbr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]
2025-03-04 Add v4
    [kbxIrBlaster-B_Cu.gbr, kbxIrBlaster-B_Mask.gbr, kbxIrBlaster-B_Paste.gbr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]

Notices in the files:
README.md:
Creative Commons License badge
